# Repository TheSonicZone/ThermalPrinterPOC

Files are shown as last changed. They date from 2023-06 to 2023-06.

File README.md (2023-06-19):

# ThermalPrinterPOC
## _Fun with a FUJITSU printer mechanism and a MSP430G2553_
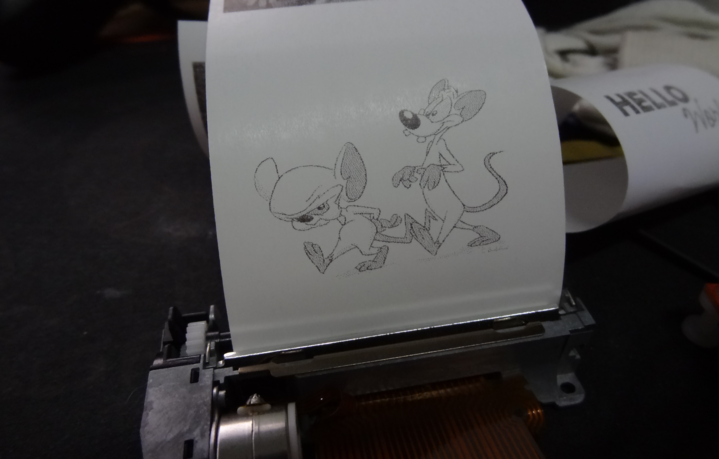
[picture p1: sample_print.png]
SAMPLE


This is a proof-of-concept to evaluate if a MSP430G2553 is capable of driving a Fujitsu FTP-628MC101 series thermal print engine
## Features

- It prints a simple graphic, 384 pixels by 245 pixels
- It drives the stepper in 1-2 phase excitation mode which leads to smooth motion

## Development and Building
This is a TI Code Composer Studio Project that is run on a MSP430 Launchpad fitted with a MSP430G2553

## How it works
The documentation on this printer mechanism is sketchy at best so allow me to put the record straight.
- The print head, is a large shift register, 384 bits wide which corresponds to the print width.
- 384 bits are clocked in serially, then they are latched to a 384 bit latch via a latch signal
- The 384 bits are arranged into 6 banks. You sequentially power on the banks with the STROBE signals to burn the paper
- You cannot try and be smart and turn all 6 STROBE signals on at once, if you try, the printer head then draws in excess of 3A and will burn either the FFC or the PC board
- Therefore the sequence is as follows
  -- shift 384 pixel bits into the shift register and latch them
  -- wait for the stepper to be in the right position (happens at 2 positions during the stepper cycle -- see code)
  -- sequence the STROBE pins, ensuring each STROBE is on for the same amount of time otherwise print density is uneven
  -- do it all again or stop if the print is completed

## Caveats
- The print head serial transfer is bit banged and incurs some delay in software. This tends to result in a thin gap between adjacent pixel rows on the printed image
- Printing BLACK with high density needs to be done at speed, otherwise the paper sticks to the platen
- Be careful of firmware crashes. If the firmware crashes or hangs while any of the STROBE signals are asserted, the print head WILL burn the paper to a crisp and burn the platen roller

## Usage
1. Program device
2. Release RESET
3. Watch it print
4. Press the user push button on the MSP-EXP430GET evaluation board to feed the paper

## License

This program is published under the terms of the GNU General Public License

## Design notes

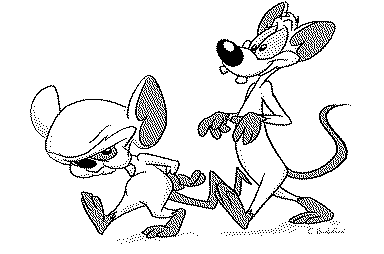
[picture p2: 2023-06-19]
pinky_brain_384_254.bmp

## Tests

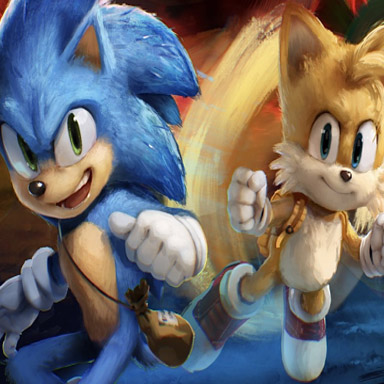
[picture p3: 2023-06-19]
test_graphics_384_384.jpg

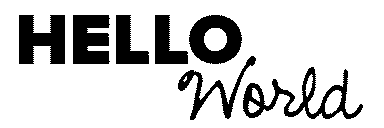
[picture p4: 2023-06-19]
test_graphics.bmp

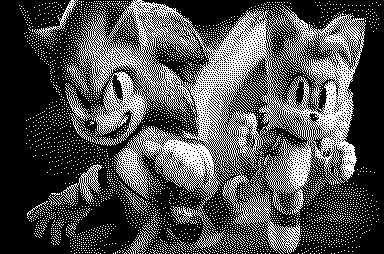
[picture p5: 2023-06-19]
test_graphics_384_254.bmp

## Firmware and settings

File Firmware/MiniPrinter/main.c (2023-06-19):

//--------------------------------------------------------------------------------------------------------
//                  Mini Printer
//      Proof of concept with Fujitsu FTP-628MCL101#50
//             and other similar thermal print mechanisms
//--------------------------------------------------------------------------------------------------------


#include <msp430.h> 
#include "timer.h"
#include "stepper.h"
#include "printhead.h"


// Variables
//-------------------------------
unsigned int timebase = 0;
unsigned int time_seconds = 0;
extern unsigned char stepper_enable;
extern unsigned char line_marker;
extern unsigned char stepper_hold;
unsigned char linecnt = 0;
extern unsigned char print_enabled;
unsigned char bufferloaded = false;
extern unsigned int dataoffset;


const char Graphic1 []={
            0x00,0x00,0x00,0x00,0x00,0x00,0x00,0x00,0x00,0x00,0x00,0x00,0x00,0x00,0x00,0x00,
            0x00,0x00,0x00,0x00,0x00,0x00,0x00,0x00,0x00,0x00,0x00,0x00,0x00,0x00,0x00,0x00,
            0x00,0x00,0x00,0x00,0x00,0x00,0x00,0x00,0x00,0x00,0x00,0x00,0x00,0x00,0x00,0x00,
            0x00,0x00,0x00,0x00,0x00,0x00,0x00,0x00,0x00,0x00,0x00,0x00,0x00,0x00,0x00,0x00,
            0x00,0x00,0x00,0x00,0x00,0x00,0x00,0x00,0x00,0x00,0x00,0x00,0x00,0x00,0x00,0x00,
            0x00,0x00,0x00,0x04,0x00,0x00,0x00,0x00,0x00,0x00,0x00,0x00,0x00,0x00,0x00,0x00,
            0x00,0x00,0x00,0x00,0x00,0x00,0x00,0x00,0x00,0x00,0x00,0x00,0x00,0x00,0x00,0x00,
            0x00,0x00,0x00,0x00,0x00,0x00,0x00,0x00,0x00,0x00,0x00,0x00,0x00,0x00,0x00,0x00,
            0x00,0x00,0x00,0x76,0x00,0x00,0x00,0x00,0x00,0x00,0x00,0x00,0x00,0x00,0x00,0x00,
            0x00,0x00,0x00,0x00,0x00,0x00,0x00,0x00,0x00,0x00,0x00,0x00,0x00,0x00,0x00,0x00,
            0x00,0x00,0x00,0x00,0x00,0x00,0x00,0x00,0x00,0x00,0x00,0x00,0x00,0x00,0x00,0x00,
            0x00,0x00,0x03,0xD1,0x00,0x00,0x00,0x00,0x00,0x00,0x00,0x00,0x00,0x00,0x00,0x00,
            0x00,0x00,0x00,0x00,0x00,0x00,0x00,0x00,0x00,0x00,0x00,0x00,0x00,0x00,0x00,0x00,
            0x00,0x00,0x00,0x00,0x00,0x00,0x00,0x00,0x00,0x00,0x00,0x00,0x00,0x00,0x00,0x00,
            0x00,0x00,0x07,0x19,0x80,0x00,0x00,0x00,0x00,0x00,0x00,0x00,0x00,0x00,0x00,0x00,
            0x00,0x00,0x00,0x00,0x00,0x00,0x00,0x00,0x00,0x00,0x00,0x00,0x00,0x00,0x00,0x00,
            0x00,0x00,0x00,0x00,0x00,0x00,0x00,0x00,0x00,0x00,0x00,0x00,0x00,0x00,0x00,0x00,
            0x00,0x00,0x1C,0xA9,0x00,0x00,0x00,0x00,0x00,0x00,0x00,0x00,0x00,0x00,0x00,0x00,
            0x00,0x00,0x00,0x00,0x00,0x00,0x00,0x00,0x00,0x00,0x00,0x00,0x00,0x00,0x00,0x00,
            0x00,0x00,0x00,0x00,0x00,0x00,0x00,0x00,0x00,0x00,0x00,0x00,0x00,0x00,0x00,0x00,
            0x00,0x00,0x72,0x99,0x80,0x00,0x00,0x00,0x00,0x00,0x00,0x00,0x00,0x00,0x00,0x00,
            0x00,0x00,0x00,0x00,0x00,0x00,0x00,0x00,0x00,0x00,0x00,0x00,0x00,0x00,0x00,0x00,
            0x00,0x00,0x00,0x00,0x00,0x00,0x00,0x00,0x00,0x00,0x00,0x00,0x00,0x00,0x00,0x00,
            0x00,0x00,0xEA,0x59,0x00,0x00,0x00,0x00,0x00,0x00,0x00,0x00,0x00,0x00,0x00,0x00,
            0x00,0x00,0x00,0x00,0x00,0x00,0x00,0x00,0x00,0x00,0x00,0x00,0x00,0x00,0x00,0x00,
            0x00,0x00,0x00,0x00,0x00,0x00,0x00,0x00,0x00,0x00,0x00,0x00,0x00,0x00,0x00,0x00,
            0x00,0x01,0x89,0x51,0x00,0x00,0x00,0x00,0x00,0x00,0x00,0x00,0x00,0x00,0x00,0x00,
            0x00,0x00,0x00,0x00,0x00,0x00,0x00,0x00,0x00,0x00,0x00,0x00,0x00,0x00,0x00,0x00,
            0x00,0x00,0x00,0x00,0x00,0x00,0x00,0x00,0x00,0x00,0x00,0x00,0x00,0x00,0x00,0x00,
            0x00,0x07,0x55,0x31,0x00,0x00,0x00,0x00,0x00,0x00,0x00,0x00,0x00,0x00,0x00,0x00,
            0x00,0x00,0x00,0x00,0x00,0x00,0x00,0x00,0x00,0x00,0x00,0x00,0x00,0x00,0x00,0x00,
            0x00,0x00,0x00,0x00,0x00,0x00,0x00,0x00,0x00,0x00,0x00,0x00,0x00,0x00,0x00,0x00,
            0x00,0x0E,0x49,0x73,0x00,0x00,0x00,0x00,0x00,0x00,0x00,0x00,0x00,0x00,0x00,0x00,
            0x00,0x00,0x00,0x00,0x00,0x00,0x00,0x00,0x00,0x00,0x00,0x00,0x00,0x00,0x00,0x00,
            0x00,0x00,0x00,0x00,0x00,0x00,0x00,0x00,0x00,0x00,0x00,0x00,0x00,0x00,0x00,0x00,
            0x00,0x19,0x2A,0xA2,0x00,0x00,0x00,0x00,0x00,0x00,0x00,0x00,0x00,0x00,0x00,0x00,
            0x00,0x00,0x00,0x00,0x00,0x00,0x00,0x00,0x00,0x00,0x00,0x00,0x00,0x00,0x00,0x00,
            0x00,0x00,0x00,0x00,0x00,0x00,0x00,0x00,0x00,0x00,0x00,0x00,0x00,0x00,0x00,0x00,
            0x00,0x35,0x52,0x6F,0xE0,0x00,0x00,0x00,0x00,0x00,0x00,0x00,0x00,0x00,0x00,0x00,
            0x00,0x00,0x00,0x00,0x00,0x00,0x00,0x00,0x00,0x00,0x00,0x00,0x00,0x00,0x00,0x00,
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
            };

//-------------------------------------------------------------------------------------
// Main Function
//-------------------------------------------------------------------------------------
int main(void){
	WDTCTL = WDTPW | WDTHOLD;	// stop watchdog timer

    // Configure and calibrate system clock
    //--------------------------------------
    DCOCTL = 0;                                  // Select lowest DCOx and MODx settings
    BCSCTL1 = CALBC1_16MHZ;                       // Set range
    DCOCTL = CALDCO_16MHZ;                        // Set DCO step + modulation */
    BCSCTL2 = 0x00;



    // Configure ports
    //------------------
    P1DIR = 0xF7;                               // P1.0 - P1.4 = Stepper motor control signals (P1.3 is push button input)
    P1OUT = 0x80;                               // P1.0 - P1.4 = OFF    P1.7 = 1 (LATCH SIGNAL TO PRINTHEAD)
    P2DIR = 0xFF;                               //
    P2OUT = 0x00;                               // Initialise
    P2SEL2 = P2SEL2 & 0x3F;
    P2SEL = P2SEL & 0x3F;                       // P2.7 and P2.6 made GPIO


    // Configure WDT as systick timer
    //--------------------------------

    WDTCTL = WDT_MDLY_0_5 ;                     // Enable WDT with period of 500uS
    IE1 |= WDTIE;                               // Enable WDT interrupt



    // Enable interrupts
    //-----------------------------
    __enable_interrupt();                       // Enable System interrupts

    // System Initialisation
    //-----------------------------
    InitTimerSystem();
	InitStepper();

//	LineBufferLoad();               // Load the test pattern just once to check if that's what consumes the bulk of the CPU cycles.

	// Test Print Here
	dataoffset = 0;
	Delay(10000);                   // Power on delay
	stepper_enable = true;          // Turn motor on
	// Count several lines before printing
	line_marker = false;
	for(linecnt = 0; linecnt < 50; linecnt++){
	    while(line_marker == false){
	        ;
	    }
	    line_marker = false;
	}

    // Header whitespace has passed, begin print
	for(linecnt = 0; linecnt < 254; linecnt++){
	    while(line_marker == false){
	        if(bufferloaded == false){
	            LineBufferLoad(Graphic1);
	            dataoffset += 48;
	            bufferloaded = true;
	        }
	    }
	    stepper_hold = true;
	    line_marker = false;
	    Fuse();
	    stepper_hold = false;
	    bufferloaded = false;
	}

	// Finished printing
	Delay(2000);
	stepper_enable = false;
	print_enabled = false;
	stepper_hold = false;

//	LineBufferLoad();
    for(;;){
        if ((P1IN & 0x08) != 0x08){
            stepper_enable = true;
        } else {
            stepper_enable = false;
        }
    }
}



//--------------------------------------------------
// Watchdog Timer interrupt service routine
// Used here as a system timer
// Period is 65.6 uS
//---------------------------------------------------
#pragma vector=WDT_VECTOR
__interrupt void watchdog_timer(void){

    CallInISR();
    timebase++;
    if(timebase > 5){
        timebase = 0;
        // We hit here every 1mS
        time_seconds++;
        if(time_seconds > 1){  // 1 is OK for fast feeding but NOT for printing
            StepperSvc();
            time_seconds = 0;

        }
    }
}

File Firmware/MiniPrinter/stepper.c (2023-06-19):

//------------------------------------------------------------------------------------------------
//                      stepper.c
//                  Stepper motor driver via BA6845 dual 1/2 H bridge
//
//          Notes: IN12 and IN22 are technically used to enable/disable the H-bridge, the driver uses
//                 a single pin to toggle the coil between FWD and REVERSE
//------------------------------------------------------------------------------------------------

#include <msp430.h>
#include "stepper.h"
#include "printhead.h"


unsigned char stepsequence;
unsigned char stepper_enable;
unsigned char stepper_hold;
unsigned char line_marker;
unsigned char print_enabled;


//--------------------------------------------------------------------------------------
// Name: InitStepper
// Function: Initialise Stepper driver and variables
//--------------------------------------------------------------------------------------
void InitStepper(void){
    stepsequence = 0x00;
    stepper_enable = false;
    line_marker = false;
    stepper_hold = false;
    print_enabled = false;


}

//--------------------------------------------------------------------------------------
// Name: StepperSvc
// Function: Routine called in a timer interrupt to generate motor step logic
// Parameters: void
// Returns: void
//--------------------------------------------------------------------------------------
void StepperSvc(void){

    if(stepper_hold == true){
        return;
    }
    if(stepper_enable == true){
        // Run in 1-2 phase excitation mode
        switch(stepsequence){
        case 0x00:
            P1OUT &= ~IN11;
            P1OUT |= IN12;
            P1OUT &= ~IN21;
            P1OUT &= ~IN22;
            break;

        case 0x01:
            P1OUT &= ~IN11;
            P1OUT |= IN12;
            P1OUT &= ~IN21;
            P1OUT |= IN22;
            break;

        case 0x02:
            P1OUT &= ~IN11;
            P1OUT &= ~IN12;
            P1OUT &= ~IN21;
            P1OUT |= IN22;
            break;

        case 0x03:
            P1OUT |= IN11;
            P1OUT |= IN12;
            P1OUT &= ~IN21;
            P1OUT |= IN22;
            line_marker = true;
            break;

        case 0x04:
            P1OUT |= IN11;
            P1OUT |= IN12;
            P1OUT &= ~IN21;
            P1OUT &= ~IN22;
            break;

        case 0x05:
            P1OUT |= IN11;
            P1OUT |= IN12;
            P1OUT |= IN21;
            P1OUT |= IN22;
            break;

        case 0x06:
            P1OUT &= ~IN11;
            P1OUT &= ~IN12;
            P1OUT |= IN21;
            P1OUT |= IN22;
            break;

        case 0x07:
            P1OUT &= ~IN11;
            P1OUT |= IN12;
            P1OUT |= IN21;
            P1OUT |= IN22;
            line_marker = true;
            break;

        }
        stepsequence--;
        if(stepsequence == 0xFF){
            stepsequence = 0x07;
        }
    } else {
        P1OUT &= ~IN11;
        P1OUT &= ~IN12;
        P1OUT &= ~IN21;
        P1OUT &= ~IN22;
    }


}

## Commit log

2023-06-19 ** FIRST WORKING VERSION ** Proof of concept that prints a small graphic. The latest version prints Pinky and the Brain on the paper
    [MiniPrinter.PrjPCB, MiniPrinter1.0..PcbDoc, MiniPrinter1.0.SchDoc]
2023-06-19 Update README.md
    Added small detail about Evaluation Board
2023-06-19 Update README.md
    Added image of sample print
2023-06-19 Added sample print image
